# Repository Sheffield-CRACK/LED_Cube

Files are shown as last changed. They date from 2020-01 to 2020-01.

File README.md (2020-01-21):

# Trackellite
Software for desktop satellite tracking toy. 
Will query for TLE files daily, and produce a grid of how many satellites are where in real time. This uses an arduino and a series of SIPO shift registers to drive the actual cube. The python script `send_cube.py` contains a function, `conv2byte_vect`, which converts a numpy array (or list) to something that can be transmitted to the arduino. Something like this:

```python
# Start the serial connection
ser = serial.Serial('/dev/cu.wchusbserial72', 9600, timeout=.1)
print("Waiting for Arduino to start...")
time.sleep(2)
print("\n\n\nReady to start transmitting!")

# Bouncing Box
di = 1
i = 1
while True:
    if i == 6 or i == 0:
        di = -di
    i += di

    temp_data = np.array(data, copy=True)
    temp_data[i:i+2, i:i+2, i:i+2] = 1

    writeable_data = conv2byte_vect(temp_data)
    ser.write(writeable_data)

    time.sleep(0.1)

ser.close()
```

## TLE, and the basics of the Raspberry Pi's job
This is how satellite/orbital junk ephemerides are reported. It's basically just the position of the thing at two moments in time, then you extrapolate out from there. I'm using ported NASA code to do this - if it's good enough for NASA it's good enough for me, and I cant be arsed to write the code for that. They're somehow still using a system built to work with punchcards? Fortran users must feel vindicated.

Once a day, the full list of TLE files from [here](https://celestrak.com/NORAD/elements/) is downloaded, and each is checked to see if it passes overhead to the user. If it does, the pi puts it in its pocket, but if it doesn't it gets chucked away. Then, the pi starts constantly checking what's overhead and generating a grid, with the number of objects in each cell. The grid corresponds to the volume of space above the user. The plan is to then use this to light up the grid, corresponding to how the space junk is positioned above the user.

# Checklist:
- [DONE] [SLOW, DONT USE] Query N2YO for satellites
- [DONE] Compute my own satellite locations
- [DONE] Figure out how to plug the grid into LED matrix
  - LED matrix, c.f. [here](https://www.instructables.com/id/Led-Cube-8x8x8/)?
- [DONE] Get the software running on a raspberry pi (3B+? or will a zero work?)
- Breadboard a prototype LED matrix [DONE] and control it [TODO]
  - This needs to be done differently. I was going to do it straight off the pi, but thinking about it, it'd be better to have one (or several) arudinos handle the LEDs, so that the pi can focus on the satellites. An arduino MEGA has like, 56 GPIO pins or something, so one of those could easily handle a 4x5x5 grid (4 + 25 pins needed). Slap some transistors on that and we'd be good to go I think, though I'd probably want a breadboard hat for the arduino, vs *learning how to make a PCB(!!)* and getting that manufactured. And there's no way I'm doing this with loose wires.
- [DONE] Wire together a 3D grid of LEDs
  - I bought some stainless steel wire to use as conductor and scaffold - but solder doesn't stick to it >:(
  - I need something else. Bare steel wire maybe? Or use the scaffold and wrap a current carrier around it? [This worked]
- [DONE] Control the cube from python, through the arduino driver.
- [lol] Make a nice case
- Add a screen? Links to satellites on web trackers for more info?

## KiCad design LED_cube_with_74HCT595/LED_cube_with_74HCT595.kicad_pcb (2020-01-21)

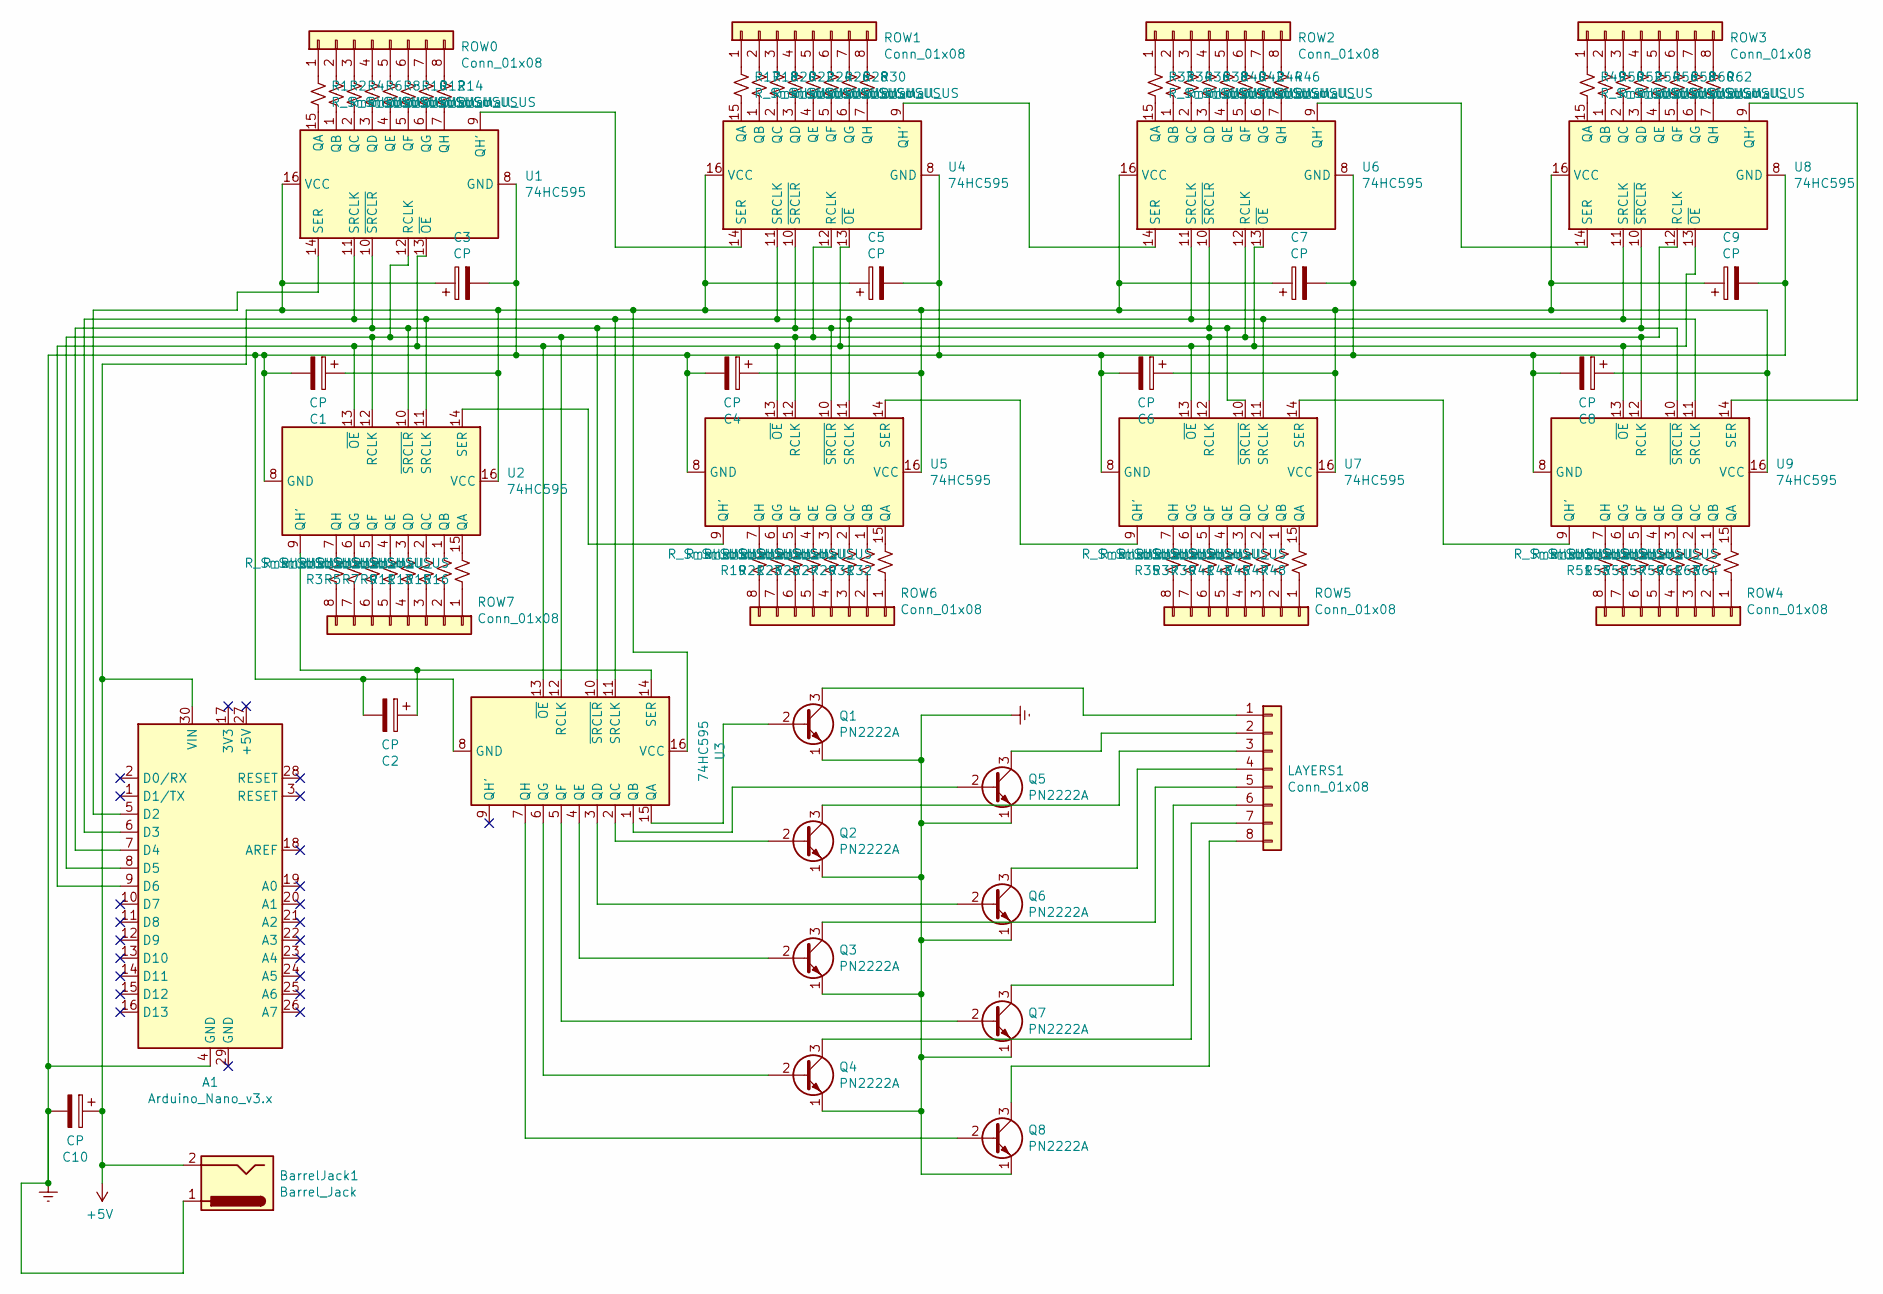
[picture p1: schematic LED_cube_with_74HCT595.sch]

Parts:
A1: Arduino_Nano_v3.x; Arduino_Nano
BarrelJack1: Barrel_Jack; BarrelJack_CUI_PJ-102AH_Horizontal
C1, C2, C3, C4, C5, C6, C7, C8, C9, C10: CP; CP_Radial_D4.0mm_P2.00mm
LAYERS1: Conn_01x08; PinHeader_1x08_P2.00mm_Vertical
Q1, Q2, Q3, Q4, Q5, Q6, Q7, Q8: PN2222A; TO-92_Inline
R1, R2, R3, R4, R5, R6, R7, R8, R9, R10, R11, R12, R13, R14, R15, R16, R17, R18, R19, R20, R21, R22, R23, R24, R25, R26, R27, R28, R29, R30, R31, R32, R33, R34, R35, R36, R37, R38, R39, R40, R41, R42, R43, R44, R45, R46, R47, R48, R49, R50, R51, R52, R53, R54, R55, R56, R57, R58, R59, R60, R61, R62, R63, R64: R_Small_US; R_Axial_DIN0204_L3.6mm_D1.6mm_P5.08mm_Horizontal
ROW0, ROW1, ROW2, ROW3, ROW4, ROW5, ROW6, ROW7: Conn_01x08; PinHeader_1x08_P2.00mm_Vertical
U1, U2, U3, U4, U5, U6, U7, U8, U9: 74HC595; DIP-16_W7.62mm_LongPads

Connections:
+5V: A1.30 (VIN), BarrelJack1.2, C1.1, C3.1, C4.1, C5.1, C6.1, C7.1, C8.1, C9.1, C10.1, U1.16 (VCC), U2.16 (VCC), U3.16 (VCC), U4.16 (VCC), U5.16 (VCC), U6.16 (VCC), U7.16 (VCC), U8.16 (VCC), U9.16 (VCC)
Earth: A1.4 (GND), BarrelJack1.1, C1.2, C2.2, C3.2, C4.2, C5.2, C6.2, C7.2, C8.2, C9.2, C10.2, Q1.1 (E), Q2.1 (E), Q3.1 (E), Q4.1 (E), Q5.1 (E), Q6.1 (E), Q7.1 (E), Q8.1 (E), U1.8 (GND), U2.8 (GND), U3.8 (GND), U4.8 (GND), U5.8 (GND), U6.8 (GND), U7.8 (GND), U8.8 (GND), U9.8 (GND)
unnamed: A1.5 (D2), U1.14 (SER)
unnamed: A1.6 (D3), U1.11 (SRCLK), U2.11 (SRCLK), U3.11 (SRCLK), U4.11 (SRCLK), U5.11 (SRCLK), U6.11 (SRCLK), U7.11 (SRCLK), U8.11 (SRCLK), U9.11 (SRCLK)
unnamed: A1.7 (D4), U1.10 (~SRCLR), U2.10 (~SRCLR), U3.10 (~SRCLR), U4.10 (~SRCLR), U5.10 (~SRCLR), U6.10 (~SRCLR), U7.10 (~SRCLR), U8.10 (~SRCLR), U9.10 (~SRCLR)
unnamed: A1.8 (D5), U1.12 (RCLK), U2.12 (RCLK), U3.12 (RCLK), U4.12 (RCLK), U5.12 (RCLK), U6.12 (RCLK), U7.12 (RCLK), U8.12 (RCLK), U9.12 (RCLK)
unnamed: A1.9 (D6), U1.13 (~OE), U2.13 (~OE), U3.13 (~OE), U4.13 (~OE), U5.13 (~OE), U6.13 (~OE), U7.13 (~OE), U8.13 (~OE), U9.13 (~OE)
unnamed: C2.1, U2.9 (QH'), U3.14 (SER)
unnamed: LAYERS1.1, Q1.3 (C)
unnamed: LAYERS1.2, Q5.3 (C)
unnamed: LAYERS1.3, Q2.3 (C)
unnamed: LAYERS1.4, Q6.3 (C)
unnamed: LAYERS1.5, Q3.3 (C)
unnamed: LAYERS1.6, Q7.3 (C)
unnamed: LAYERS1.7, Q4.3 (C)
unnamed: LAYERS1.8, Q8.3 (C)
unnamed: Q1.2 (B), U3.15 (QA)
unnamed: Q2.2 (B), U3.2 (QC)
unnamed: Q3.2 (B), U3.4 (QE)
unnamed: Q4.2 (B), U3.6 (QG)
unnamed: Q5.2 (B), U3.1 (QB)
unnamed: Q6.2 (B), U3.3 (QD)
unnamed: Q7.2 (B), U3.5 (QF)
unnamed: Q8.2 (B), U3.7 (QH)
unnamed: R1.1, ROW0.1
unnamed: R1.2, U1.15 (QA)
unnamed: R2.1, ROW0.2
unnamed: R2.2, U1.1 (QB)
unnamed: R3.1, ROW7.8
unnamed: R3.2, U2.7 (QH)
unnamed: R4.1, ROW0.3
unnamed: R4.2, U1.2 (QC)
unnamed: R5.1, ROW7.7
unnamed: R5.2, U2.6 (QG)
unnamed: R6.1, ROW0.4
unnamed: R6.2, U1.3 (QD)
unnamed: R7.1, ROW7.6
unnamed: R7.2, U2.5 (QF)
unnamed: R8.1, ROW0.5
unnamed: R8.2, U1.4 (QE)
unnamed: R9.1, ROW7.5
unnamed: R9.2, U2.4 (QE)
unnamed: R10.1, ROW0.6
unnamed: R10.2, U1.5 (QF)
unnamed: R11.1, ROW7.4
unnamed: R11.2, U2.3 (QD)
unnamed: R12.1, ROW0.7
unnamed: R12.2, U1.6 (QG)
unnamed: R13.1, ROW7.3
unnamed: R13.2, U2.2 (QC)
unnamed: R14.1, ROW0.8
unnamed: R14.2, U1.7 (QH)
unnamed: R15.1, ROW7.2
unnamed: R15.2, U2.1 (QB)
unnamed: R16.1, ROW7.1
unnamed: R16.2, U2.15 (QA)
unnamed: R17.1, ROW1.1
unnamed: R17.2, U4.15 (QA)
unnamed: R18.1, ROW1.2
unnamed: R18.2, U4.1 (QB)
unnamed: R19.1, ROW6.8
unnamed: R19.2, U5.7 (QH)
unnamed: R20.1, ROW1.3
unnamed: R20.2, U4.2 (QC)
unnamed: R21.1, ROW6.7
unnamed: R21.2, U5.6 (QG)
unnamed: R22.1, ROW1.4
unnamed: R22.2, U4.3 (QD)
unnamed: R23.1, ROW6.6
unnamed: R23.2, U5.5 (QF)
unnamed: R24.1, ROW1.5
unnamed: R24.2, U4.4 (QE)
unnamed: R25.1, ROW6.5
unnamed: R25.2, U5.4 (QE)
unnamed: R26.1, ROW1.6
unnamed: R26.2, U4.5 (QF)
unnamed: R27.1, ROW6.4
unnamed: R27.2, U5.3 (QD)
unnamed: R28.1, ROW1.7
unnamed: R28.2, U4.6 (QG)
unnamed: R29.1, ROW6.3
unnamed: R29.2, U5.2 (QC)
unnamed: R30.1, ROW1.8
unnamed: R30.2, U4.7 (QH)
unnamed: R31.1, ROW6.2
unnamed: R31.2, U5.1 (QB)
unnamed: R32.1, ROW6.1
unnamed: R32.2, U5.15 (QA)
unnamed: R33.1, ROW2.1
unnamed: R33.2, U6.15 (QA)
unnamed: R34.1, ROW2.2
unnamed: R34.2, U6.1 (QB)
unnamed: R35.1, ROW5.8
unnamed: R35.2, U7.7 (QH)
unnamed: R36.1, ROW2.3
unnamed: R36.2, U6.2 (QC)
unnamed: R37.1, ROW5.7
unnamed: R37.2, U7.6 (QG)
unnamed: R38.1, ROW2.4
unnamed: R38.2, U6.3 (QD)
unnamed: R39.1, ROW5.6
unnamed: R39.2, U7.5 (QF)
unnamed: R40.1, ROW2.5
unnamed: R40.2, U6.4 (QE)
unnamed: R41.1, ROW5.5
unnamed: R41.2, U7.4 (QE)
unnamed: R42.1, ROW2.6
unnamed: R42.2, U6.5 (QF)
unnamed: R43.1, ROW5.4
unnamed: R43.2, U7.3 (QD)
unnamed: R44.1, ROW2.7
unnamed: R44.2, U6.6 (QG)
unnamed: R45.1, ROW5.3
unnamed: R45.2, U7.2 (QC)
unnamed: R46.1, ROW2.8
unnamed: R46.2, U6.7 (QH)
unnamed: R47.1, ROW5.2
unnamed: R47.2, U7.1 (QB)
unnamed: R48.1, ROW5.1
unnamed: R48.2, U7.15 (QA)
unnamed: R49.1, ROW3.1
unnamed: R49.2, U8.15 (QA)
unnamed: R50.1, ROW3.2
unnamed: R50.2, U8.1 (QB)
unnamed: R51.1, ROW4.8
unnamed: R51.2, U9.7 (QH)
unnamed: R52.1, ROW3.3
unnamed: R52.2, U8.2 (QC)
unnamed: R53.1, ROW4.7
unnamed: R53.2, U9.6 (QG)
unnamed: R54.1, ROW3.4
unnamed: R54.2, U8.3 (QD)
unnamed: R55.1, ROW4.6
unnamed: R55.2, U9.5 (QF)
unnamed: R56.1, ROW3.5
unnamed: R56.2, U8.4 (QE)
unnamed: R57.1, ROW4.5
unnamed: R57.2, U9.4 (QE)
unnamed: R58.1, ROW3.6
unnamed: R58.2, U8.5 (QF)
unnamed: R59.1, ROW4.4
unnamed: R59.2, U9.3 (QD)
unnamed: R60.1, ROW3.7
unnamed: R60.2, U8.6 (QG)
unnamed: R61.1, ROW4.3
unnamed: R61.2, U9.2 (QC)
unnamed: R62.1, ROW3.8
unnamed: R62.2, U8.7 (QH)
unnamed: R63.1, ROW4.2
unnamed: R63.2, U9.1 (QB)
unnamed: R64.1, ROW4.1
unnamed: R64.2, U9.15 (QA)
unnamed: U1.9 (QH'), U4.14 (SER)
unnamed: U2.14 (SER), U5.9 (QH')
unnamed: U4.9 (QH'), U6.14 (SER)
unnamed: U5.14 (SER), U7.9 (QH')
unnamed: U6.9 (QH'), U8.14 (SER)
unnamed: U7.14 (SER), U9.9 (QH')
unnamed: U8.9 (QH'), U9.14 (SER)

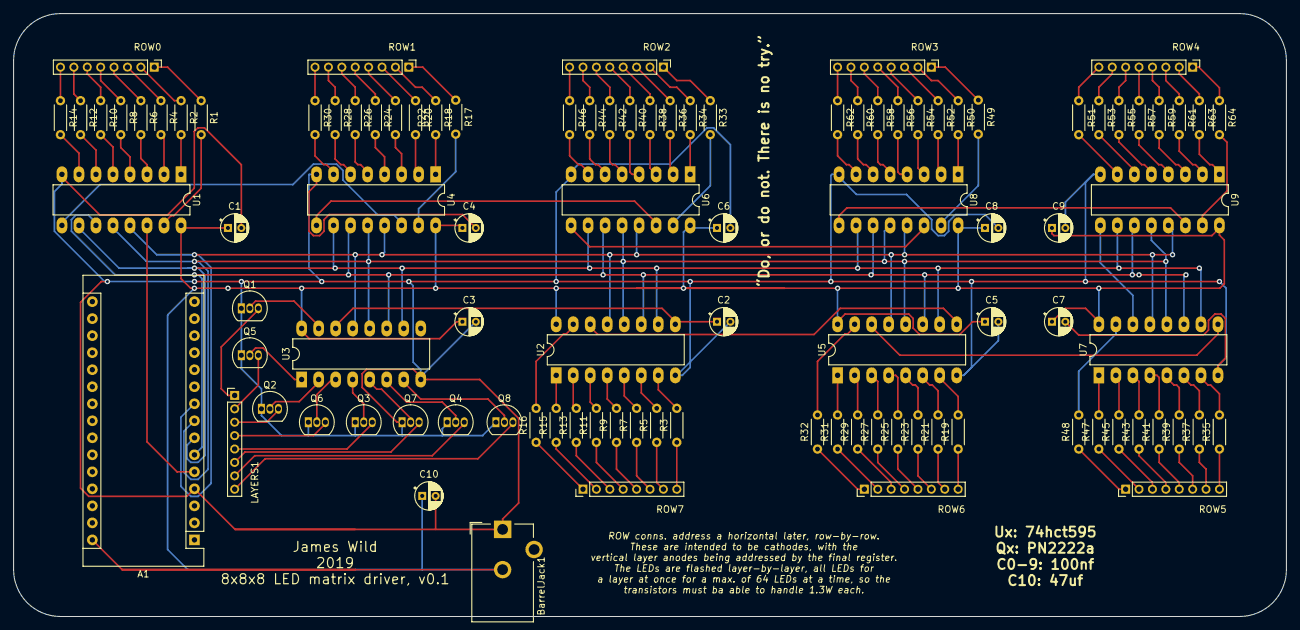
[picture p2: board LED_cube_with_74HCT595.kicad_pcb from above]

Board: 2 copper layers, 190.0 x 90.0 mm, 102 parts (0 on the bottom side), 159 nets.

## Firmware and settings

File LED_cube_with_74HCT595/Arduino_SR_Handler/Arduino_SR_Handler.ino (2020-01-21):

//Pin connected to ST_CP of 74HC595
int latchPin = 5;
//Pin connected to SH_CP of 74HC595
int clockPin = 3;
//Pin connected to DS of 74HC595
int dataPin = 2;

int oePin = 6;
int mrPin = 4;

// How many 74hct595 are in cascade
const int N_REGISTERS = 8;

// How long to illuminate each layer
const int FLASH_PERIOD = 3;

// Layer counter
int layer = 0;

// For recieving data
byte recieved = 0;
int last_layer_recieved = 0;
int BAUDRATE = 9600;

// This array actually does the legwork
byte cube[N_REGISTERS*N_REGISTERS];

// Initial state
char initial[8*N_REGISTERS*N_REGISTERS] = {
        '1', '0', '0', '0', '0', '0', '0', '1',
        '0', '0', '0', '0', '0', '0', '0', '0',
        '0', '0', '0', '0', '0', '0', '0', '0',
        '0', '0', '0', '0', '0', '0', '0', '0',
        '0', '0', '0', '0', '0', '0', '0', '0',
        '0', '0', '0', '0', '0', '0', '0', '0',
        '0', '0', '0', '0', '0', '0', '0', '0',
        '1', '0', '0', '0', '0', '0', '0', '1',

        '1', '0', '0', '0', '0', '0', '0', '1',
        '0', '0', '0', '0', '0', '0', '0', '0',
        '0', '0', '0', '0', '0', '0', '0', '0',
        '0', '0', '0', '0', '0', '0', '0', '0',
        '0', '0', '0', '0', '0', '0', '0', '0',
        '0', '0', '0', '0', '0', '0', '0', '0',
        '0', '0', '0', '0', '0', '0', '0', '0',
        '1', '0', '0', '0', '0', '0', '0', '1',

        '1', '0', '0', '0', '0', '0', '0', '1',
        '0', '0', '0', '0', '0', '0', '0', '0',
        '0', '0', '1', '1', '1', '1', '0', '0',
        '0', '0', '1', '0', '0', '1', '0', '0',
        '0', '0', '1', '0', '0', '1', '0', '0',
        '0', '0', '1', '1', '1', '1', '0', '0',
        '0', '0', '0', '0', '0', '0', '0', '0',
        '1', '0', '0', '0', '0', '0', '0', '1',

        '1', '0', '0', '0', '0', '0', '0', '1',
        '0', '0', '0', '0', '0', '0', '0', '0',
        '0', '0', '1', '0', '0', '1', '0', '0',
        '0', '0', '0', '1', '1', '0', '0', '0',
        '0', '0', '0', '1', '1', '0', '0', '0',
        '0', '0', '1', '0', '0', '1', '0', '0',
        '0', '0', '0', '0', '0', '0', '0', '0',
        '1', '0', '0', '0', '0', '0', '0', '1',

        '1', '0', '0', '0', '0', '0', '0', '1',
        '0', '0', '0', '0', '0', '0', '0', '0',
        '0', '0', '1', '0', '0', '1', '0', '0',
        '0', '0', '0', '1', '1', '0', '0', '0',
        '0', '0', '0', '1', '1', '0', '0', '0',
        '0', '0', '1', '0', '0', '1', '0', '0',
        '0', '0', '0', '0', '0', '0', '0', '0',
        '1', '0', '0', '0', '0', '0', '0', '1',

        '1', '0', '0', '0', '0', '0', '0', '1',
        '0', '0', '0', '0', '0', '0', '0', '0',
        '0', '0', '1', '1', '1', '1', '0', '0',
        '0', '0', '1', '0', '0', '1', '0', '0',
        '0', '0', '1', '0', '0', '1', '0', '0',
        '0', '0', '1', '1', '1', '1', '0', '0',
        '0', '0', '0', '0', '0', '0', '0', '0',
        '1', '0', '0', '0', '0', '0', '0', '1',

        '1', '0', '0', '0', '0', '0', '0', '1',
        '0', '0', '0', '0', '0', '0', '0', '0',
        '0', '0', '0', '0', '0', '0', '0', '0',
        '0', '0', '0', '0', '0', '0', '0', '0',
        '0', '0', '0', '0', '0', '0', '0', '0',
        '0', '0', '0', '0', '0', '0', '0', '0',
        '0', '0', '0', '0', '0', '0', '0', '0',
        '1', '0', '0', '0', '0', '0', '0', '1',

        '1', '0', '0', '0', '0', '0', '0', '1',
        '0', '0', '0', '0', '0', '0', '0', '0',
        '0', '0', '0', '0', '0', '0', '0', '0',
        '0', '0', '0', '0', '0', '0', '0', '0',
        '0', '0', '0', '0', '0', '0', '0', '0',
        '0', '0', '0', '0', '0', '0', '0', '0',
        '0', '0', '0', '0', '0', '0', '0', '0',
        '1', '0', '0', '0', '0', '0', '0', '1',
};

void setup() {
  // set pins to output because they are 
  // addressed in the main loop
  pinMode(latchPin, OUTPUT);
  pinMode(dataPin, OUTPUT);  
  pinMode(clockPin, OUTPUT);

  pinMode(mrPin, OUTPUT);
  pinMode(oePin, OUTPUT);
  

  digitalWrite(oePin, LOW);
  digitalWrite(mrPin, HIGH);
  digitalWrite(clockPin, LOW);
  
  Serial.begin(BAUDRATE);
  Serial.write("I've been reset...\n");
  
  char2binary();
}

void loop() {
  if (Serial.available()) recieveBytes();
  
  writeLayer(layer);
  
  // Iterate up through the layers
  layer += 1;
  layer = layer % N_REGISTERS;
}


// Convert the initial state to the binary arrays
void char2binary(){
  // Convert the layer to it's binary representation
  for (int i=0; i<N_REGISTERS*N_REGISTERS; i++){
    // Reset the row to all off
    cube[i] = 0;
    
    // Loop through this layer and convert to binary
    cube[i] += initial[8*i] - 48;
    for (int j=1; j<8; j++){
      cube[i] <<= 1;
      cube[i] += initial[8*i + j] - 48;
    }
  }
}

void addressLayer(int layer){
  registerWrite(layer, true);
}

void registerWrite(int whichPin, int whichState) {
// the bits you want to send
  byte bitsToSend = 0;

  // turn off the output so the pins don't light up
  // while you're shifting bits:
  digitalWrite(latchPin, LOW);

  // turn on the next highest bit in bitsToSend:
  bitWrite(bitsToSend, whichPin, whichState);

  // shift the bits out:
  shiftOut(dataPin, clockPin, LSBFIRST, bitsToSend);
}


// Shove the rows array out to the shift registers
void writeLayer(int mylayer){
  // Write the rows to the registers
  // Disable pushing the output
  digitalWrite(latchPin, false);
  
  // Address the desired layer
  registerWrite(mylayer, true);
  
  // Push the rows of the layer out
  for (int i=mylayer*N_REGISTERS; i<(1+mylayer)*N_REGISTERS; i++){
    shiftOut(dataPin, clockPin, LSBFIRST, cube[i]);
  }
  
  // Push the output
  digitalWrite(latchPin, true);
}


// Recieve all the bytes that were pushed across 
// and push them into the layers array
void recieveBytes(){
  while(Serial.available()){
    recieved = Serial.read();
    
//    Serial.print("Recieved: ");
//    Serial.println(recieved, BIN);

    cube[last_layer_recieved] = recieved;
    last_layer_recieved++;
    last_layer_recieved = last_layer_recieved % (N_REGISTERS*N_REGISTERS);
  }
}

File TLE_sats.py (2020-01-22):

'''Uses python-sgp4 to calculate which satellites will cross my zenith today.
Then, make a list of those satellites.
Print a list periodically of the satellites overhead.

requires this repo to be installed:
https://github.com/brandon-rhodes/python-sgp4
https://github.com/satellogic/orbit-predictor
'''

import glob
import os
import shutil
from time import clock
from datetime import datetime, timedelta

import geocoder
import numpy as np
from orbit_predictor import (angles, coordinate_systems, exceptions, keplerian,
                             locations, predictors, sources, utils)
from sgp4.earth_gravity import wgs84
from sgp4.io import twoline2rv

try:
    from urllib2 import urlopen
except:
    from urllib.request import urlopen

from send_cube import connect_cube, send_cube

OVERHEAD_LIMIT = 10. # Degrees

TLE_URLS = ('http://celestrak.com/NORAD/elements/weather.txt',
            'http://celestrak.com/NORAD/elements/resource.txt',
            'https://www.celestrak.com/NORAD/elements/cubesat.txt',
            'http://celestrak.com/NORAD/elements/stations.txt',
            'https://www.celestrak.com/NORAD/elements/sarsat.txt',
            'https://www.celestrak.com/NORAD/elements/noaa.txt',
            'https://www.celestrak.com/NORAD/elements/amateur.txt',
            'https://www.celestrak.com/NORAD/elements/engineering.txt')


def fetch(urls):
    """Fetch TLE from internet and save it to `destination`."""
    print("Fetching TLE data...")
    # TODO: play nicely when recollecting data
    try:
        shutil.rmtree("TLE_data")
    except:
        pass
    os.mkdir('TLE_data')

    for url in urls:
        destination = url.split('/')[-1]
        destination = os.path.join("TLE_data", destination)

        with open(destination, "w", encoding="utf-8") as dest:
            response = urlopen(url)
            dest.write(response.read().decode("utf-8"))

def update_passing_sats(dt=1):
    # Where am I?
    g = geocoder.ip('me')
    lat, lon = g.latlng
    me = locations.Location('me', lat, lon, 0)

    # Get the current time.
    now = datetime.utcnow()
    # Get tomorrow, as the limit on when to check
    tomorrow = now + timedelta(days=dt)
    print('I want to find satellites that pass overhead between:\n', now, '\n', tomorrow)

    # Get a database of satellites.
    fetch(TLE_URLS)
    created_files = glob.glob("TLE_data/*")
    print("TLE files:\n{}".format(created_files))

    # Now read that data into my TLE database
    database = sources.MemoryTLESource()
    # Also track all my satellite IDs
    sat_IDs = []
    print("Parsing TLE data...")
    for fname in created_files:
        with open(fname, 'r') as f:
            while True:
                name = f.readline().strip()
                if name == '':
                    break

                sat_IDs.append(name)
                tle_1 = f.readline().strip()
                tle_2 = f.readline().strip()

                tle = (tle_1, tle_2)

                database.add_tle(name, tle, now)
    print("Done!")

    print("Checking all satellites to see which transit overhead in the next 24 hours...")
    alt_lim = abs(90 - OVERHEAD_LIMIT) # Degrees

    passes = []
    will_pass = []

    for ID in sat_IDs:
        try:
            predictor = predictors.TLEPredictor(ID, database)
            pred = predictor.get_next_pass(
                location=me,
                when_utc=now,
                aos_at_dg=alt_lim,
                limit_date=tomorrow
            )
            print("The object {} will pass over {} deg at:\n--> {}\n".format(ID, alt_lim, pred))
            will_pass.append(ID)
            passes.append(pred)
        except AssertionError as e:
            pass
            # print(e)
        except exceptions.NotReachable as e:
            pass
            # print(e)
        except exceptions.PropagationError as e:
            pass
            # print(e)


    # print(will_pass)
    print("\n\nFound {} satellites that will pass through the top {} degrees above lat, lon: {}, {} within the next {} day(s)\n\n\n".format(
        len(will_pass), 90-alt_lim, lat, lon, dt
    ))


    with open('passing_sats.txt', 'w') as f:
        to_write = '\n'.join(will_pass)
        f.write(to_write)

    for ID, pred in zip(will_pass, passes):
        print("{}\n\n".format(pred))

    return database

def sat_locations(database,
                  mylat, mylon,
                  time=None,
                  lat_bins=8, lon_bins=8,
                  alt_edges=[9e99, 30000, 20000, 10000, 5000, 2000, 1000, 0],
                  quiet=True):
    '''For the satellite IDs in passing_sats.txt, check their current location. Then,
    fill in a grid of how many satellites are in each cell of a grid.

    Inputs:
    -------
    database, MemoryTLESource
        The orbit_predictor TLE database, populated with satellites
    time, datetime.datetime, optional
        The time to calculate the grid for. If None, use datetime.datetime.utcnow(). Requires UTC
    lat_bins, int, optional
        The number of latitude bins. Used to construct a numpy linspace for the bin edges.
    lon_bins, int, optional
        The same, for longitude
    alt_edges, iterable of floats, optional
        A list of the altitude bins.

    Output:
    -------
    grid, 3D numpy array
        A grid populated with the number of satellites per cell, at the current time.
    '''

    if time is None:
        time = datetime.utcnow()

    # What are my bin edges?
    altrange = abs(OVERHEAD_LIMIT)
    lat_edges = np.linspace(-altrange, +altrange, lat_bins)
    lon_edges = np.linspace(-altrange, +altrange, lon_bins)

    # Init an empty grid.
    grid = np.zeros((len(alt_edges), lat_bins, lon_bins), dtype=int)

    # I might be interested in which satellite is currently overhead
    overhead_now = []

    with open('passing_sats.txt', 'r') as f:
        for line in f:
            if not quiet:
                print("\n\n-------------------------------------------------------------------------------------\n\n")
            ID = line.strip()

            # create this satellite's predictor
            predictor = predictors.TLEPredictor(ID, database)

            # The positions are returned in Earth-centric, Earth fixed coords. I need to convert those.
            ecef_location = predictor.get_only_position(time)

            ### Convert ECEF to LLA ###
            lat, lon, alt = coordinate_systems.ecef_to_llh(ecef_location)

            if not quiet:
                print("satellite ID: {}".format(ID))
                print("ECEF coords (x, y, z): {}, {}, {}".format(*ecef_location))
                print("LLS coords (lat, lon, alt): {}, {}, {}".format(lat, lon, alt))

            # transform lat, lon, to relative to me
            dlat = lat - mylat
            dlon = lon - mylon

            if not quiet:
                print("Relative to me, the satellite is at {}, {}, {}".format(dlat, dlon, alt))
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

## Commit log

2019-07-31 First look at LED logic. Upload a shopping list
    [LED Cube Shopping list.xlsx]
2019-07-31 Updated spreadsheet
    [LED Cube Shopping list.xlsx]
2019-08-03 Began to impliment the LED handling software
    [LED Cube Shopping list.xlsx]
2019-08-04 Moved LED handler to class
2019-08-04 Making decisions about how to deal out the pin numbers
2019-08-05 Threaded the LED handler
2020-01-16 Updated to use shift registers
    [LED Cube Shopping list.xlsx]
2020-01-16 Ignore spreadsheets
    [LED Cube Shopping list.xlsx]
2020-01-21 Uploaded PCB design. Uploaded rain animation
    [LED_cube_with_74HCT595-B_Cu.gbl, LED_cube_with_74HCT595-B_Mask.gbs, LED_cube_with_74HCT595-B_SilkS.gbo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]
2020-01-21 Tried to make the connect_cube detect the arduino automagically
2020-01-22 Fixed non-working connect_cube code
    [TLE_sats.py, rain.py, send_cube.py]
